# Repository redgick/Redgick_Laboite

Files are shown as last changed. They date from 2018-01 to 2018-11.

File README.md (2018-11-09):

# Redgick_Laboite
*laboite* is a connected clock that displays a lot of information from the Internetz.



## Requirement

 * [Redgick_GFX](https://github.com/redgick/Redgick_GFX), the core graphics library;
 * [WiFiManager](https://github.com/tzapu/WiFiManager);
 * **ESP8266HTTPClient** by Markus Sattler
 * **ArduinoJson** by Benoit Blanchon

## Installation

[Download this repository](https://github.com/redgick/Redgick_Laboite/archive/master.zip) and unzip it into the Arduino libraries folder on your computer. You should rename the folder `Redgick_Laboite-master` in `Redgick_Laboite`.

In the Arduino IDE, look at `File/Examples/Redgick_Laboite` folder to load an example sketch.

## Building _laboîte maker_

### Material

 * 1 x NodeMcu _V2_ or _V3_;
 * 2 x MAX7219 Dot Matrix Modules;
 * 1 x frame 3D printed ([download 3D model](https://github.com/redgick/Redgick_Laboite/blob/master/CAD/laboite_maker_frame_v1.9.stl?raw=true));
 * 1 x PMMA screen laser cutted ([download 2D model](https://github.com/redgick/Redgick_Laboite/blob/master/CAD/laboite_maker_screen_v1.9.svg?raw=true));
 * 1 x colson collar.

The CAD models of the frame and the screen can be edited on [Tinkercad](https://www.tinkercad.com/things/hslmXMSMxwP)

### Schematic

_laboîte maker_ as been tested with two types of NodeMCU : _V2_ and _V3_.
Both come with the chip _ESP-12E_. If you compare the pin layout of the _V3_, there’s only a tiny difference to the _V2_ layout. _V3_ use one of the two reserve pins for USB power out and the other for an additional GND.

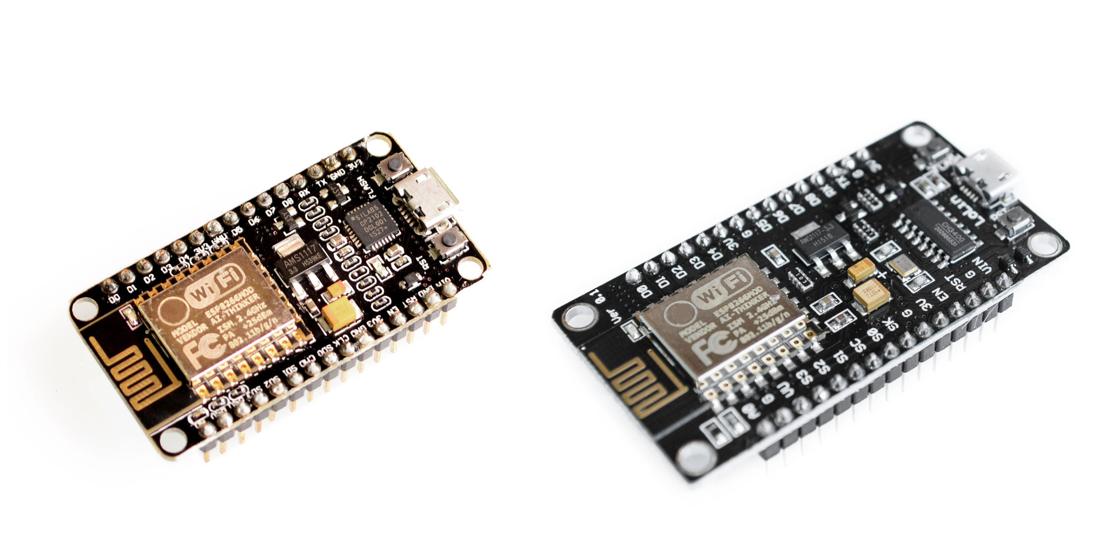
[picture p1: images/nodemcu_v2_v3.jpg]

_NodeMCU V2 / NodeMCU V3_

<table>
  <tr>
    <th colspan=2>NodeMCU V2</th><th colspan=2>NodeMCU V3</th><th>LED Matrix</th>
  </tr>
  <tr>
    <th>Pin</th><th>GPIO</th><th>Pin</th><th>GPIO</th><th>Pin</th>
  </tr>
  <tr>
  <td>Vin (+5V)</td><td>-</td><td>VV (+5V)</td><td>-</td><td>+12V</td>
  </tr>
  <tr>
    <td>GND</td><td>-</td><td>GND</td><td>-</td><td>GND</td>
  </tr>
  <tr>
    <td>D7</td><td>GPIO13</td><td>D7</td><td>GPIO13</td><td>DIN</td>
  </tr>
  <tr>
    <td>D8</td><td>GPIO15</td><td>D8</td><td>GPIO15</td><td>CS</td>
  </tr>
  <tr>
    <td>D5</td><td>GPIO14</td><td>D5</td><td>GPIO14</td><td>CLK</td>
  </tr>
</table>

 * MAX7219 Dot Matrix Modules should be connected together in serial. Only input pins are welded on the modules, so start by welding output pins on the upper MAX7219 Dot Matrix Module.
 * Then insert the Colson collar in the frame to fasten the NodeMCU on the rear side of the frame.
 * Insert MAX7219 Dot Matrix Modules in the frame and plug the PMMA screen on it.
 * Connect the MAX7219 Dot Matrix Modules and the NodeMCU following the schematic bellow :

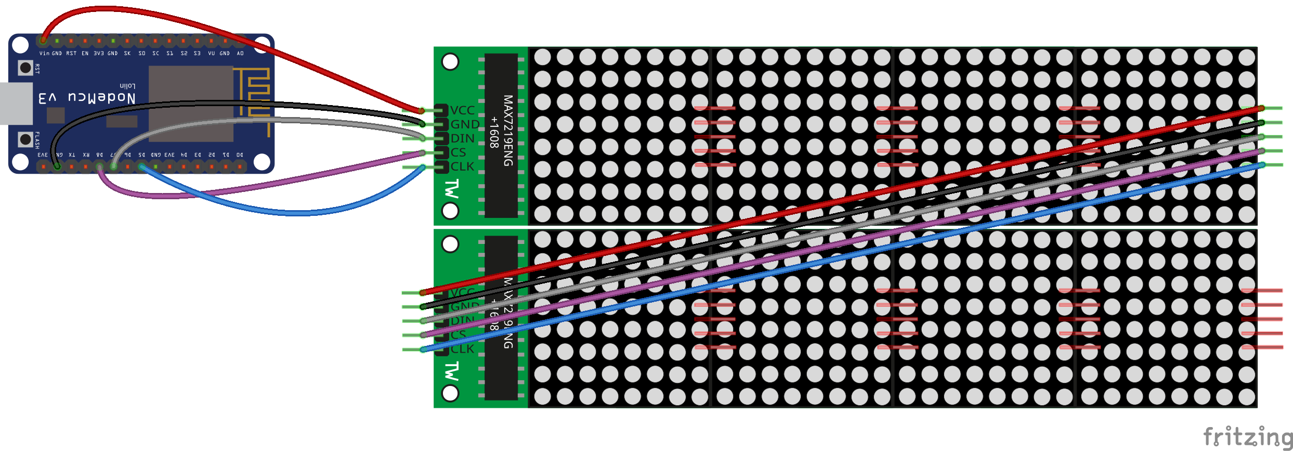
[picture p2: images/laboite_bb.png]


### lenuage.io
 * Create an account in [lenuage.io](https://lenuage.io/) and add a new _boîte_. An API Key is automatically generated.
 
### Firmware
 * Start [Arduino IDE](https://www.arduino.cc/en/Main/Software) and open `File > Preferences` window.
 * Enter `http://arduino.esp8266.com/stable/package_esp8266com_index.json` into `Additional Board Manager URLs` field.
 * Open `Tools > Board: > Boards Manager...` menu and find __ESP8266 by ESP8266 Community__ and install it.
 * Select `Tools > Board > NodeMCU 1.0 (ESP-12E Module)`.
 * Open library manager from `Sketch > Include library > Manage Libraries...` and find __ArduinoJson by Benoit Blanchon__ and install the latest __version 5__ (do not install a beta version 6).
 * Then find __WifiManager by tzapu__ and install the stable version _v0.12.0_.
 * Download [Redgick_GFX libraries](https://github.com/redgick/Redgick_GFX), copy and past __Redgick-GFX__ and __Redgick_MatrixMax72XX__ into your Arduino library folder.
 * Download [Redgick-Laboite](https://github.com/redgick/Redgick_Laboite) into your Arduino lbrary folder. Remove the trailling  extension (_-master_) of the library folder name.
 * Open `File > Exemples > Redgick_laboite > laboite_maker_edition`
 * First click on `Verify/Compile`, if an error message appears, get sure that you have correctly placed the files with the right name.
 * Replace `00000000-0000-0000-0000-000000000000` with your API key
 * Connect the NodeMCU, upload and enjoy !

### WiFi
 * At the first boot, _laboîte_ create an WiFi access point named "laboite". Connect to it with your smartphone, open a navigator à http://192.168.4.1 and set the SSID and Password of you WiFi network.
 * _laboîte_ will reboot and automatically connect to the given WiFi network. That's it !

### Going further ...
Explore _lenuage.io_ interface to configure apps and have fun !

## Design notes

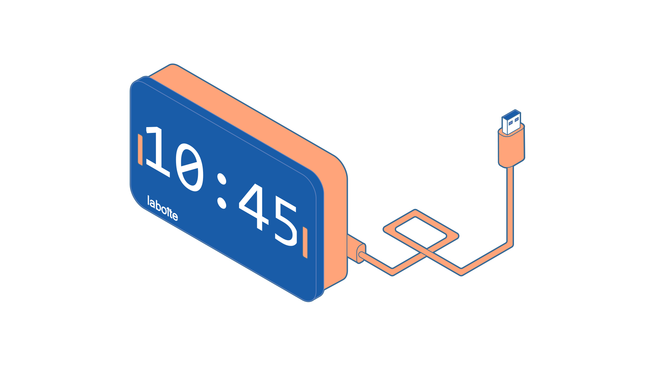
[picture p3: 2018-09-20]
images/laboite.png

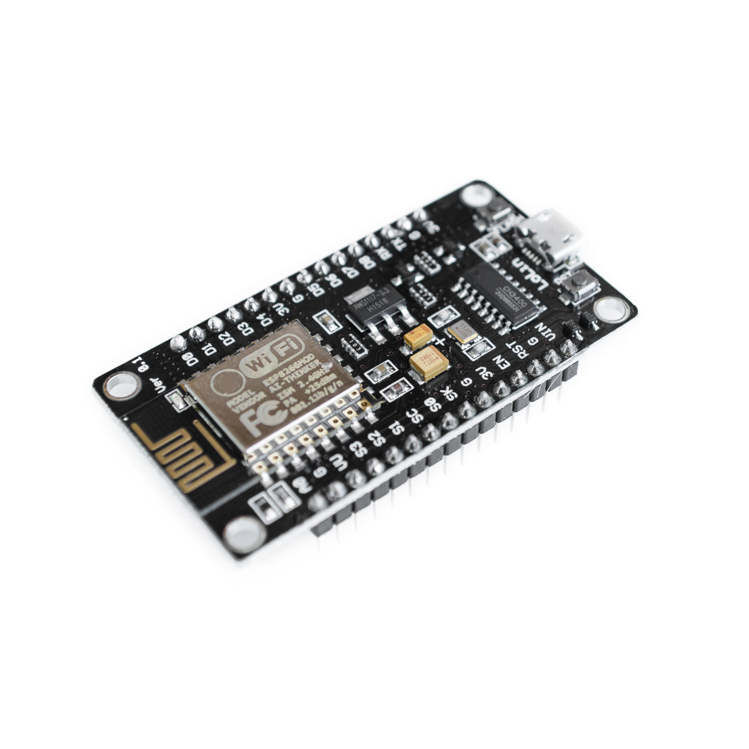
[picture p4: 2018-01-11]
images/nodemcu.jpg

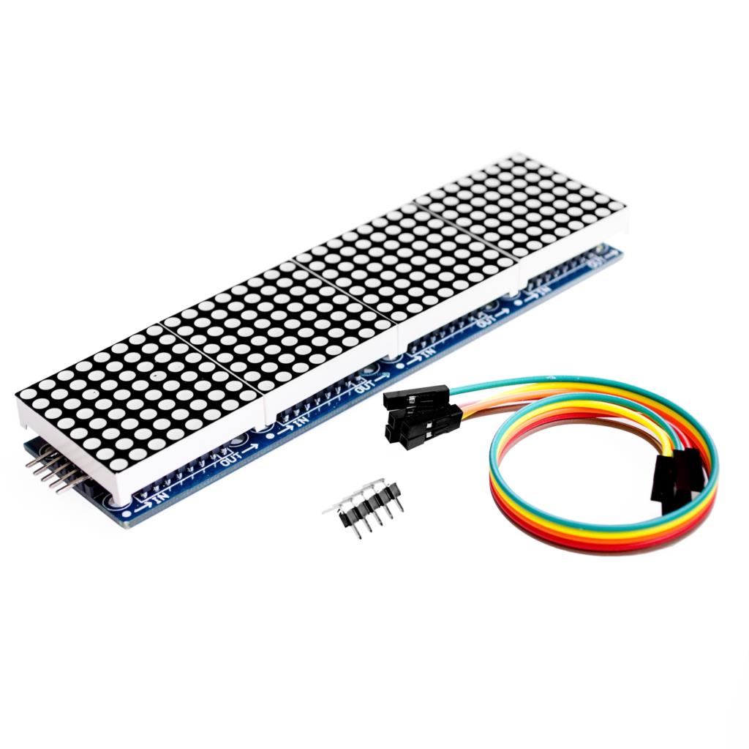
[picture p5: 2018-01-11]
images/max7219.jpg

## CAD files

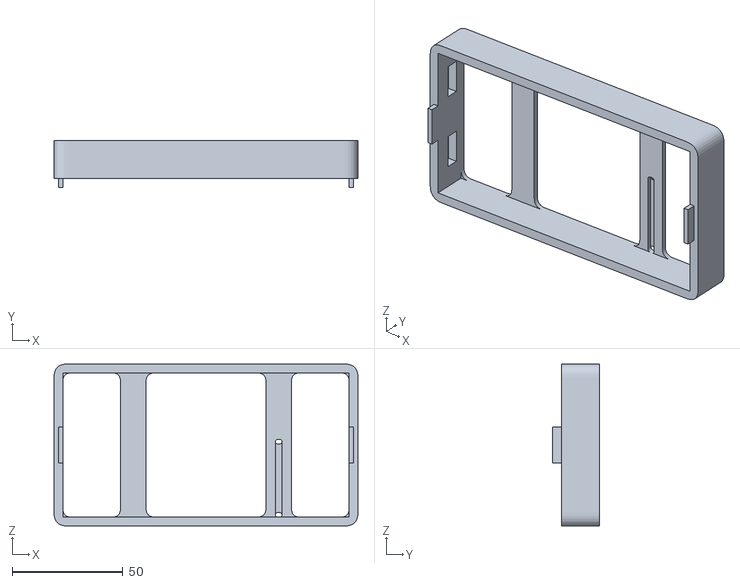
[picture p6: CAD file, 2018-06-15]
CAD/laboite_maker_frame_v1.9.stl
137.0 x 21.0 x 73.0

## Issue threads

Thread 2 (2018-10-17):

Pas de défilement des messages

Jaxom99, 2018-10-17:
Bonjour,
J'ai créé ma boite "maker" avec un node MCU V2 de chez Amica, et un écran 2*(8*32) en série.
Problème : les messages plus long que l'écran ne défilent pas. C'est un peu limitant. Les transitions entre tuiles ne sont pas prises en compte, en revanche la luminosité oui.

J'ai bien suivi tout le wiki, j'ai créé un compte sur lenuage.io et j'ai flashé avec l'IDE Arduino sur mon macOS 10.11. (El Capitan) et les biblios indiquées.
Déjà eu le souci ? Besoin d'info en plus ?
Merci d'avance pour la réponse !

Jaxom99, 2019-02-04:
Petite relance, car j'ai toujours le souci, quelque soit l'app utilisée.

Jaxom99, 2019-03-12:
Après discussion avec @jlebunetel , il s'agit d'un problème de mémoire disponible dans l'ESP8266. La fonction de défilement est juste indisponible sur cette plateforme. 😢
Affaire conclue !

Closed 2019-03-12.

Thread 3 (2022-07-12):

Error setting up MDNS responder

HuguesT, 2022-07-12:
Bonjour ,

J'ai un ESP32 Adafruit Feather et j'ai suivi le tutoriel qui est disponible ici :  https://github.com/laboiteproject/laboite-maker/wiki/Assembly-instructions

Mais, au démarrage j'ai une erreur "Error setting up MDNS responder!"

Est-ce que ce tuto est toujours d'actualité ?

Si non, est-ce qu'il est possible de réaliser une boite avec un ESP32 au lieu d'un ESP8266 ?

Merci !

bgaultier, 2022-07-13:
Bonjour @HuguesT,

Nous vous recommandons plutôt de suivre le [tutoriel suivant](https://docs.lenuage.io/hardware/laboite_maker/assembly_instructions/#1-creation-dun-compte-sur-lenuageio), adapté au microcontrôleur ESP32.

Bon courage 👍

—Baptiste

Closed 2022-07-13.

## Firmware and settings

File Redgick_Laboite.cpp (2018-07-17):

// include Arduino core library
#include "Arduino.h"

// include this library's description file
#include "Redgick_Laboite.h"

// include description files for other libraries used


// Constructor /////////////////////////////////////////////////////////////////
// Function that handles the creation and setup of instances

Tile::Tile() {
  _screen.init(32, 16, MONOCHROME);
  clear();
};


Lenuage::Lenuage(char* server, char* apikey, char* fingerprint = "") {
  strcpy(this->server, server);
  strcpy(this->apikey, apikey);
  strcpy(this->fingerprint, fingerprint);
  this->url = String(server) + "/boites/" + String(apikey) + "/";
};


// Public Methods //////////////////////////////////////////////////////////////
// Functions available in Redgick_GFX sketches, this library, and other libraries

void Tile::clear() {
  setId(0);
  setLastActivity(0);
  setPreviousId(0);
  setDuration(0);
  setBrightness(0);
  exist(false);
  needUpdate(false);
};


String Lenuage::getBoite() {
  String json; // buffer

  HTTPClient http;
  if (server[4] == 's') {
    http.begin(url, fingerprint);
  }
  else {
    http.begin(url);
  }
  http.addHeader("Accept", "application/json");

  int httpCode = http.GET();
  if (httpCode > 0 ){
    // HTTP header has been send and Server response header has been handled

    // file found at server
    if (httpCode == HTTP_CODE_OK) {
      json = http.getString();
    }
  }
  http.end();

  return json;
};


String Lenuage::getTileRaw(int id) {
  String json; // buffer
  String urlTile = url + "tiles/" + String(id) + "/";

#ifdef DEBUG
  Serial.println(urlTile);
#endif

  HTTPClient http;
  if (server[4] == 's') {
    http.begin(urlTile, fingerprint);
  }
  else {
    http.begin(urlTile);
  }
  http.addHeader("Accept", "application/json");

  int httpCode = http.GET();
  if (httpCode > 0 ){
    // HTTP header has been send and Server response header has been handled

    // file found at server
    if (httpCode == HTTP_CODE_OK) {
      json = http.getString();
    }
  }
  http.end();

  return json;
};


void Lenuage::updateBuffer() {
  // we create a buffer
  String json;

  // then we get a records collection
  json = getBoite();

  // Don’t reuse the same JsonBuffer
  // During is lifetime a JsonBuffer growth until it’s discarded.
  // If you try to reuse the same instance several time, it will rapidly get full.
  StaticJsonBuffer<1024> jsonBuffer;

  JsonObject& root = jsonBuffer.parseObject(json); // JsonObject alloué en mémoire dynamiquement ?
  if (!root.success()) {
#ifdef DEBUG
    Serial.println("parseObject() failed");
#endif
    return;
  }

  // on met le flag "exist" à "false"
  for (int i = 0; i < TILES_MAX_NUMBER; i++) {
    tiles[i].exist(false);
  }

  // pour chaque tuile on renseigne l'id de la tuile précédente
  uint16_t previous_id = 0;

  // on explore l'arbre json
  JsonArray& data = root["tiles"];
  for (auto tile : data) {
    JsonObject& tile_data = tile;

    uint16_t id = 0;
    uint32_t last_activity = 0;

    if (tile_data.containsKey("id")) {
      id = int(tile_data["id"]);
    }
    else {
      continue; // problème de lecture, on passe à la prochaine valeur de la boucle for
    }

    if (tile_data.containsKey("last_activity")) {
      last_activity = long(tile_data["last_activity"]);
    }
    else {
      continue; // problème de lecture, on passe à la prochaine valeur de la boucle for
    }

    // la tuile est-elle présente dans le buffer ? et si oui, à quel indice ?
    bool exist = false;
    uint8 index = 0;
    for (int i = 0; i < TILES_MAX_NUMBER; i++) {
      if (tiles[i].getId() == id) {
        exist = true;
        index = i;
        break;
      }
    }

    if (exist) {
      // la tuile existe
      // est-elle à jour ?
      if (tiles[index].getLastActivity() == last_activity) {
        // la tuile est à jour
        // ... rien à faire
      }
      else {
        // la tuile n'est pas à jour
        // on active le flag update
        tiles[index].needUpdate(true);

        // ATTENTION
        // LE JSON DE LA TUILE NE CONTIENT PAS L'INFORMATION last_activity !!!
        tiles[index].setLastActivity(last_activity);
        // ATTENTION
      }
    }
    else {
      // la tuile n'existe pas encore

      // on recherche la premiere place libre dans le buffer (s'il en reste)
      bool buffer_overflow = true;
      for (int i = 0; i < TILES_MAX_NUMBER; i++) {
        if (tiles[i].getId() == 0) {
          // une case est libre !
          buffer_overflow = false;
          index = i;
          break;
        }
      }

      // si une place est disponible
      if (not buffer_overflow) {
        // on crée la tuile
        tiles[index].setId(id);
        tiles[index].setLastActivity(last_activity);

        // on la met à jour
        tiles[index].needUpdate(true);
      }
      else {
        // le buffer est plein
        // que fait-on ?
      }
    }

    // on active le flag "exist"
    tiles[index].exist(true);
    tiles[index].setPreviousId(previous_id);
    previous_id = id;
    // remarque : la première tuile est la seule à avoir un previous_id==0 et id!=0
  }

  // on libère les tuiles pour lesquelles le flag "exist" est à "false"
  // cela correspond aux tuiles supprimées depuis la précédente mise à jour du buffer
  for (int i = 0; i < TILES_MAX_NUMBER; i++) {
    if (tiles[i].getId() != 0 and (not tiles[i].exist())) {
#ifdef DEBUG
      Serial.print("suppression de la tuile ");
      Serial.println(tiles[i].getId());
#endif
      tiles[i].clear();
    }
  }

  // mise à jour des tuiles dont le flag "update" est true
  for (int i = 0; i < TILES_MAX_NUMBER; i++) {
    if (tiles[i].needUpdate()) {
      updateTile(i);
    }
  }
};
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

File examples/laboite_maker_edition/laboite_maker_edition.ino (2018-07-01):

/*
   Firmware for the connected display "laboite maker" by Redgick.
   Create an account on "https://lenuage.io" and get an api key.
*/

// Two modules MAX7219 4 in 1 connected in series to get 32×16 LED dotmatrix
#include <Redgick_MatrixMAX72XX.h>
Redgick_MatrixMAX72XX matrix;

// We need a WiFi connection
#include <ESP8266WiFi.h>
#include <WiFiManager.h>  //https://github.com/tzapu/WiFiManager

// laboite library !
#include <Redgick_Laboite.h>

// Welcome screen
Screen welcome(32, 16, MONOCHROME); // with, height, colors);

// Backend connection
Lenuage lenuage(
  "http://lenuage.io",                      // server url
  "00000000-0000-0000-0000-000000000000",   // api key
  // the server ssl fingerprint is needed for a HTTPS connection
  // get it using the following command in a terminal:
  // echo | openssl s_client -connect lenuage.io:443 |& openssl x509 -fingerprint -noout
  "AD:4D:92:32:D3:D2:5A:C4:5B:62:B6:B4:94:BF:10:94:4F:71:A5:5A"
);

void setup() {
  // Serial initialization for debugging
  Serial.begin(9600);

  // Display initialization
  matrix.init();
  matrix.intensity(10);

  // Welcome message
  welcome.print(0, 2, "la");
  welcome.print(1, 9, "boite");
  matrix.display(welcome.getBuffer());

  // Connecting to a wifi network using WiFiManager
  WiFiManager wifiManager;
  wifiManager.autoConnect("laboite");

  // We get a connection !
  welcome.print(27, 0, "c");
  matrix.display(welcome.getBuffer());

  // First tiles buffer update
  lenuage.updateBuffer();
}

int currentId = lenuage.getNextTile(0);
void loop() {
  // Current tile displaying
  matrix.intensity(lenuage.getTile(currentId).getBrightness());
  matrix.display(lenuage.getTile(currentId).getScreen().getBuffer());

  // Top !
  unsigned long top = millis();

  if(currentId == lenuage.getNextTile(0)) {
    // Tiles buffer update
    lenuage.updateBuffer();
  
    // Debugging :
    lenuage.printBuffer();
  }
  
  // We wait before displaying the next tile
  unsigned int duration = lenuage.getTile(currentId).getDuration();
  while (millis() < top + duration)
    delay(50);

  // Which is the next tile ?
  currentId = lenuage.getNextTile(currentId);
}

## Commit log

2018-05-31 duration field : moving from seconds to milliseconds
2018-05-31 Duration en millisecondes
2018-06-15 Add frame and screen drawings V1.9
    [laboite_maker_frame_v1.9.stl]
